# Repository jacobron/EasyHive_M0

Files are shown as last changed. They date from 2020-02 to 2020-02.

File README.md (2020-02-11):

# EasyHive_M0
M0-Board Code (Arduino C++) and Hardware Files V1.3

This Board is designed for the purpose of remote and off-grid temperature and weight measurements.

# Features

* ADS1232 ADC-IC for weight reading up to two load-cells
* ATSAMD21G - CortexM0 Microcontroller - programmable with Arduino Software
* Ublox SaraN200 NB-IOT Chip for sending data via narrowband-LTE
* BQ24072 charging IC for USB/Solar and battery temperature monitoring
* DS18B20 temperatur sensor von Maxim Integrated
* Piezo Buzzer and RGB LED for user communication

The board features additional connections for I2S and I2C sensors, which are not used yet.

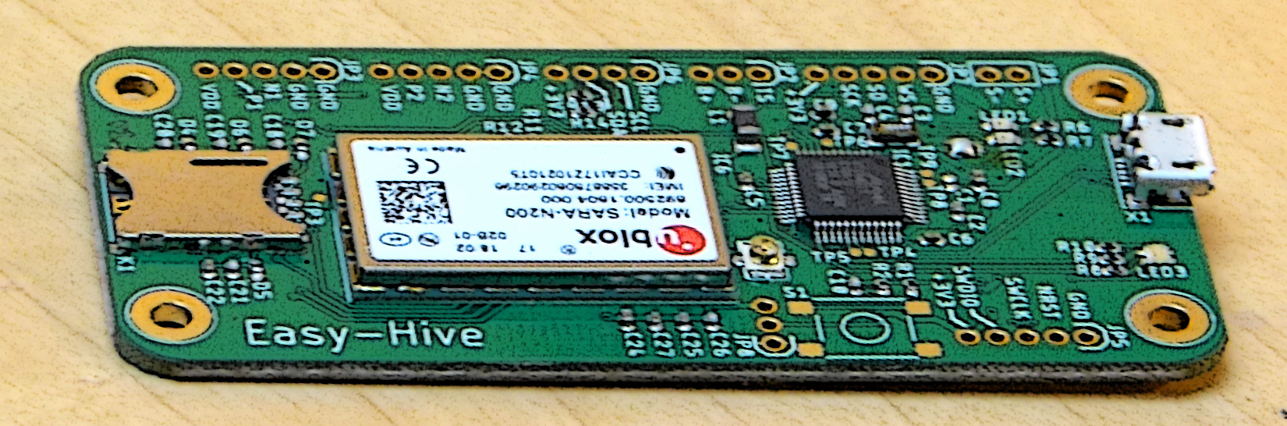
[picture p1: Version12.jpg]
BoardV12


# copyright
Software: GPL 3.0 and following versions

Hardware: CERN OHL 1.2 and following versions

This files are distributed in the hope that it will be useful,
but WITHOUT ANY WARRANTY; without even the implied warranty of
MERCHANTABILITY or FITNESS FOR A PARTICULAR PURPOSE.
See the GNU General Public License for more details.

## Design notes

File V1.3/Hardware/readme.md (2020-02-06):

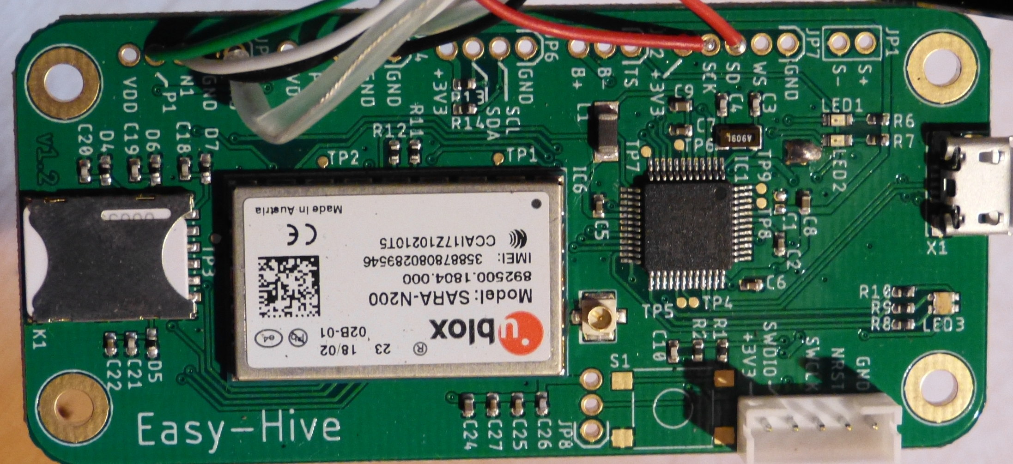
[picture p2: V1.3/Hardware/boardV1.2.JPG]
Board V1.2


# additional information
* steuckliste is missing some LEDs - we won't use them in production run as nobody see's them in the box ;-)

# copyright
CERN OHL 1.2 and following versions

This files are distributed in the hope that it will be useful,
but WITHOUT ANY WARRANTY; without even the implied warranty of
MERCHANTABILITY or FITNESS FOR A PARTICULAR PURPOSE.
See the GNU General Public License for more details.

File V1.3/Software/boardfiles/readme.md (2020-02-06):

# important information
We did not write an own Boardfile-set yet. you need to rewrite the Boardfiles from Sodaq-SFF Board which our design is based on.

more information:

[https://support.sodaq.com/getting_started/](https://support.sodaq.com/getting_started/)

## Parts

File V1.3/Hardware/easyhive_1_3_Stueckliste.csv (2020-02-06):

Id | Designator | Package | Quantity | Designation | Manufacturer | Part nr
1 | IC3 | TSSOP24 | 1 | ADS1232 | TI | ADS1232IPWR
2 | IC1 | TQFP48 | 1 | ATSAMD21G | Microchip Technology | TSAMD21G18A-AUT
3 | C2,C11,C30 | C0402 | 3 | 1u
4 | C3,C4 | C0402 | 2 | 15p
5 | C5,C6,C7,C1,C14,C15,C22,C27,C28 | C0402 | 9 | 100n
6 | C8,C9,C16,C17,C24 | C0402 | 5 | 10u
7 | L1,L2 | SM-1206 | 2 | Ferrite Bead 1k ohm 1LN | WURTH | 742792141 | auch anderer Hersteller möglich
8 | C10 | C0402 | 1 | 100p
9 | R1 | C0402 | 1 | 330
10 | R2,R8 | C0402 | 2 | 2k2
11
12 | D1,D2 | SOD123 | 2 | DIODE SCHOTTKY 20V 500MA SOD123 | ON Semiconductor | MBR0520LT | auch anderer Hersteller möglich
13 | C12,C13,C23 | C0402 | 3 | 4u7
14 | X1 | USBMICRO | 1 | USB_MICRO_SHIELD | Amphenol ICC | 10118193-0001LF
15
16
17 | IC2 | VQFN16 | 1 | BQ2407X | TI | BQ24072RGTT
18 | R3,R11,R12 | C0402 | 3 | 0R
19 | R4 | C0402 | 1 | 1k18
20 | R5 | C0402 | 1 | 680R
21
22 | R6,R7 | C0402 | 2 | 1k
23
24 | R9 | C0402 | 1 | 10k
25 | R10,R18 | C0402 | 2 | 4k7
26 | Q1 | FC135 | 1 | 32768 Hz
27 | IC4 | UMAX8 | 1 | DS18B20U | Maxim Integrated | DS18B20U+
28 | IC5 | SOT25 | 1 | XC6220B331 | Torex Semiconductor | XC6220B331MR-G
29 | K1 | 693043020611 | 1 | SimCard Holder | WÜRTH | 693043020611
30 | IC6 | SARA-N2 | 1 | SARA-N2 | U-blox | Sara N200-02B
31 | C18,C19,C20,C21,C26 | C0402 | 5 | 47p
32 | D5,D4,D6,D7,D8,D9,D10,D11,D12,D13,D14 | 0402-TVS | 11 | PESD0402-140 | Littlefuse | PESD0402-140 | auch anderer Hersteller möglich
33 | C25 | C0402 | 1 | 10n
34 | R13,R14 | C0402 | 2 | 2k
35 | F1 | 1206 | 1 | 6V/0.5A | Bel Fuse Inc | 0ZCJ0050FF2G | auch anderer Hersteller möglich
36
37
38
39
40
41 | J1 | U.FL | 1 | U.FL | Hirose | U.FL-R-SMT-1(01) | auch anderer Hersteller möglich
42
43 | P1 | PKMCS_BUZZER | 1 | PKMCS | Murata | PKMCS0909E4000-R1
44 | R16 | C0402 | 1 | 4M7
45 | R17 | C0402 | 1 | 10M
47 | R15 | C0402 | 1 | NTC 103AT 10k | Abracon | ABNTC-0402-103J-4050F-T | auch anderer Hersteller möglich
48
49 | IC7 | sot-sc70-6 | 1 | TPS22919 | TI | TPS22919DCKR

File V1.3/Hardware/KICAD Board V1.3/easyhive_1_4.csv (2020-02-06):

Id | Designator | Package | Quantity | Designation | Supplier and ref
1 | IC3 | TSSOP24 | 1 | ADS1232
2 | IC1 | TQFP48 | 1 | ATSAMD21G
3 | C2,C11,C30 | C0402 | 3 | 1u
4 | C3,C4 | C0402 | 2 | 15p
5 | C5,C6,C7,C1,C14,C15,C22,C27,C28 | C0402 | 9 | 100n
6 | C8,C9,C16,C17,C24 | C0402 | 5 | 10u
7 | L1,L2 | SM-1206 | 2 | SM-1206
8 | C10 | C0402 | 1 | 100p
9 | R1 | C0402 | 1 | 330
10 | R2,R8 | C0402 | 2 | 2k2
11 | S1 | WURTH-430 | 1 | WURTH-430
12 | D1,D2 | SOD123 | 2 | MBR0520LT
13 | C12,C13,C23 | C0402 | 3 | 4u7
14 | X1 | USBMICRO | 1 | USB_MICRO_SHIELD
15 | JP1 | 1X02_2MM | 1 | Solar
16 | JP2 | 1X03-2MM | 1 | Battery
17 | IC2 | VQFN16 | 1 | BQ2407X
18 | R3,R11,R12 | C0402 | 3 | 0R
19 | R4 | C0402 | 1 | 1k18
20 | R5 | C0402 | 1 | 680R
21 | LED1,LED2 | CHIPLED_0603 | 2 | LEDCHIPLED_0603
22 | R6,R7 | C0402 | 2 | 1k
23 | LED3 | WL-SFCX_0606 | 1 | WL-SFCD_0606_150066M153000
24 | R9 | C0402 | 1 | 10k
25 | R10,R18 | C0402 | 2 | 4k7
26 | Q1 | FC135 | 1 | 32768 Hz
27 | IC4 | UMAX8 | 1 | DS18B20U
28 | IC5 | SOT25 | 1 | XC6220B331
29 | K1 | 693043020611 | 1 | 693043020611
30 | IC6 | SARA-N2 | 1 | SARA-N2
31 | C18,C19,C20,C21,C26 | C0402 | 5 | 47p
32 | D5,D4,D6,D7,D8,D9,D10,D11,D12,D13,D14 | 0402-TVS | 11 | PESD0402-140
33 | C25 | C0402 | 1 | 10n
34 | R13,R14 | C0402 | 2 | 2k
35 | F1 | 1206 | 1 | 6V/0.5A
36 | H1,H2,H3,H4 | 2,8-PAD | 4 | MOUNT-PAD-ROUND2.8
37 | JP3 | 1X05-2MM | 1 | Sens1
38 | JP4 | 1X05-2MM | 1 | Sens2
39 | JP6 | 1X04-2MM | 1 | I2C
40 | JP5 | 1X05-2MM | 1 | SWD
41 | J1 | U.FL | 1 | U.FL
42 | JP7 | 1X05-2MM | 1 | I2S
43 | P1 | PKMCS_BUZZER | 1 | PKMCS
44 | R16 | C0402 | 1 | 4M7
45 | R17 | C0402 | 1 | 10M
46 | TP1,TP2,TP3,TP4,TP6,TP8,TP9,TP10,TP11,TP12,TP7 | TP08R | 11 | TPTP08R
47 | R15 | C0402 | 1 | NTC 103AT
48 | JP8 | 1X03-2MM | 1 | ext. DS18B20
49 | IC7 | sot-sc70-6 | 1 | TPS22919

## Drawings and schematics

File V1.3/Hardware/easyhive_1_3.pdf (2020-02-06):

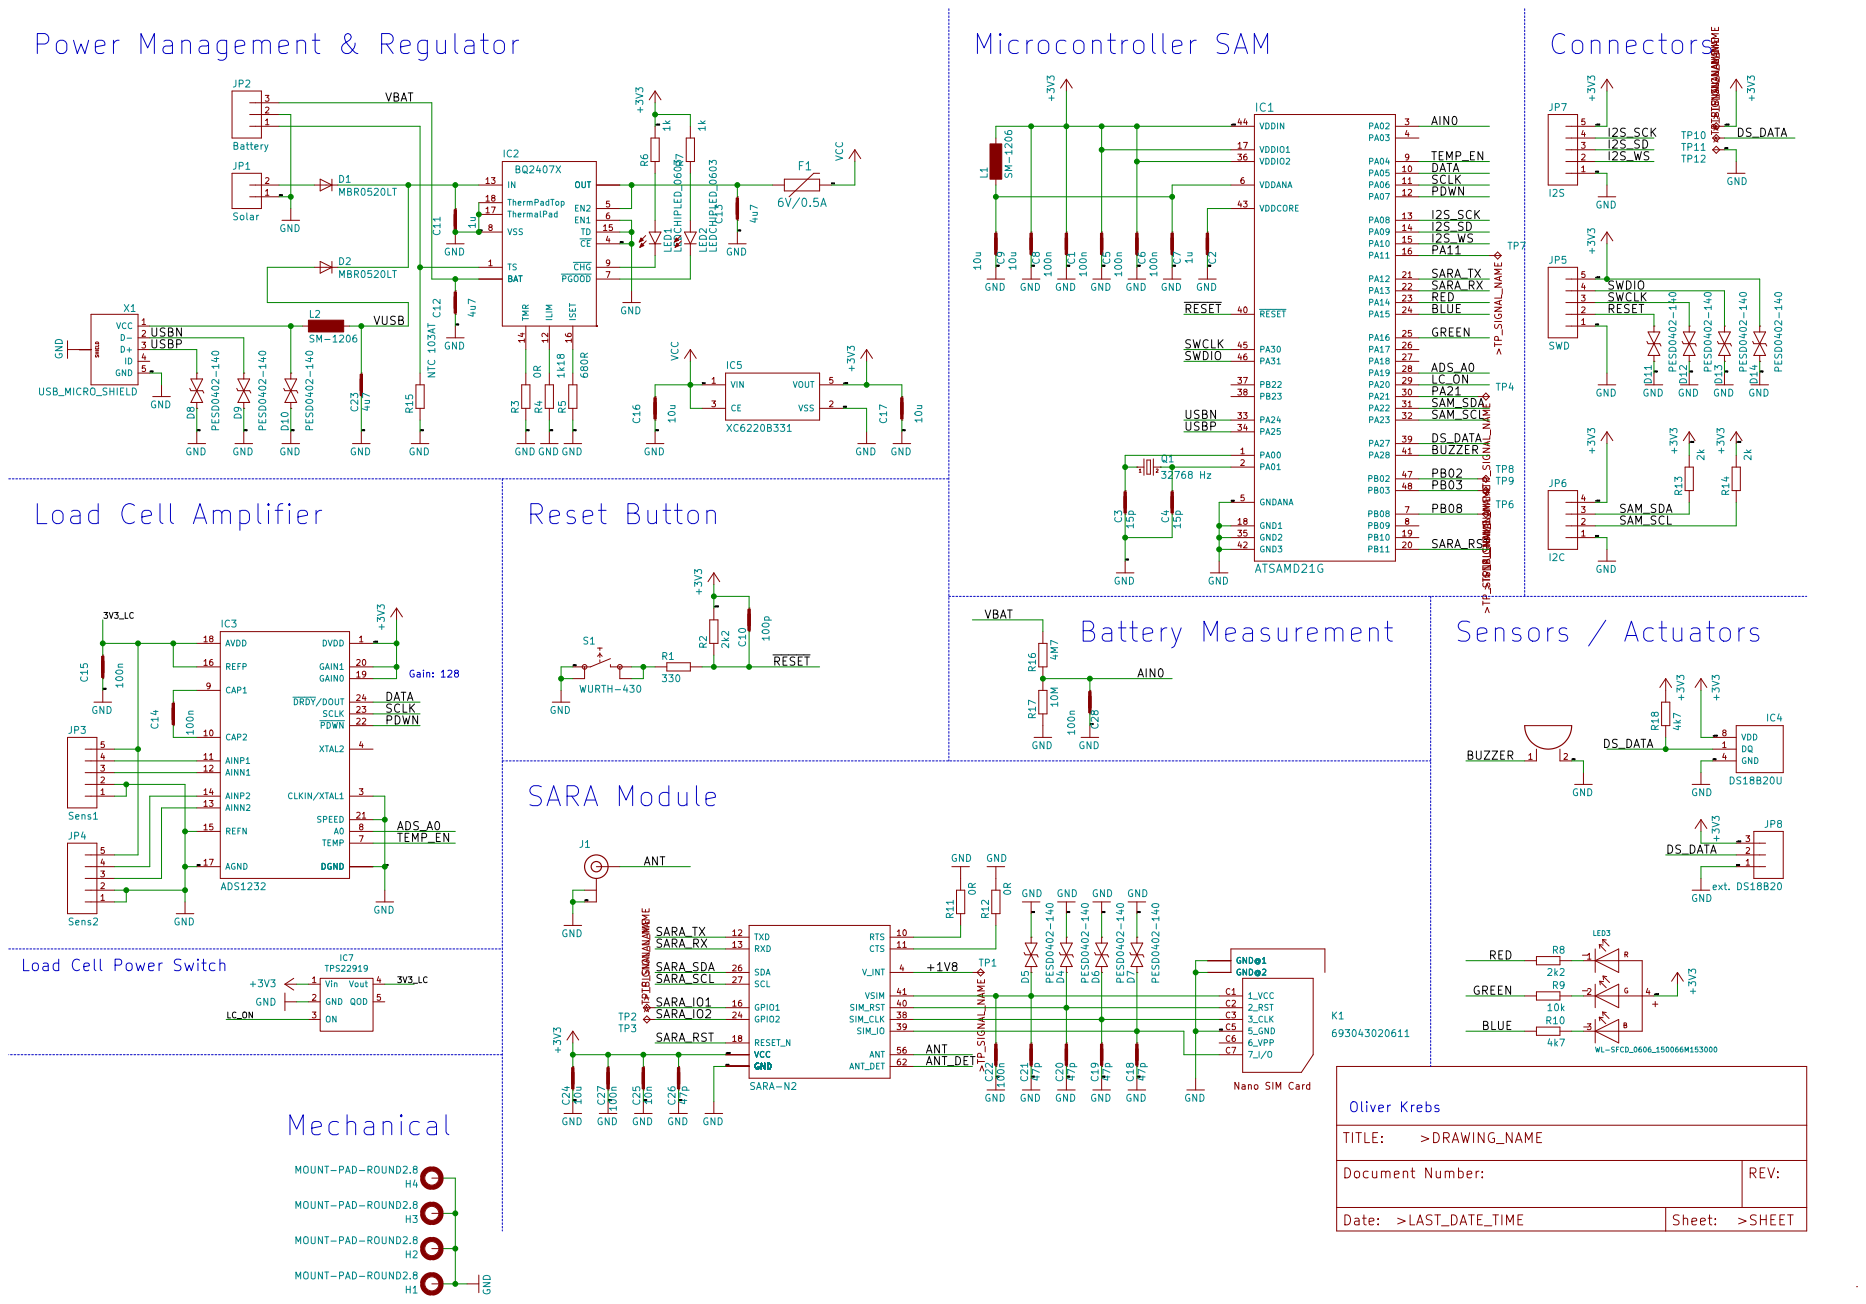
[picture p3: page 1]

Load Cell Power Switch

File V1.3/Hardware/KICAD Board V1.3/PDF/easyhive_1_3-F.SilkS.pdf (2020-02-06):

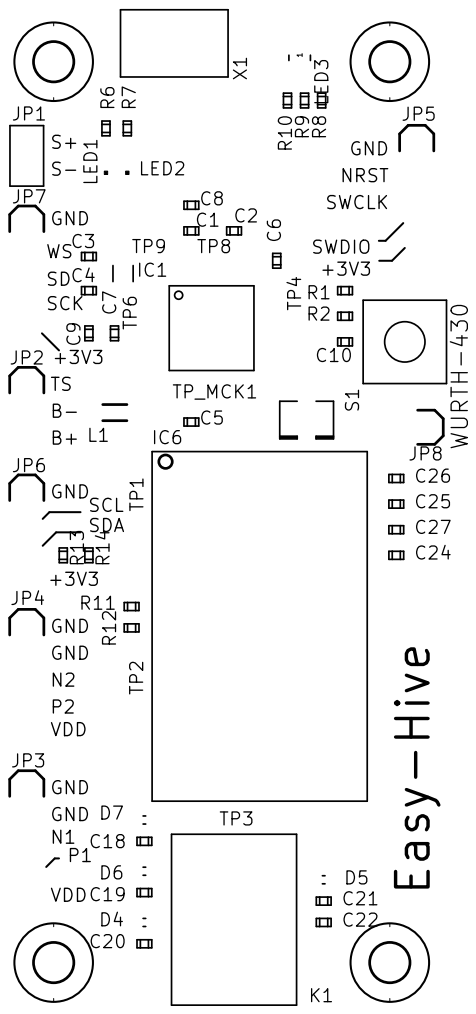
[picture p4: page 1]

+3V3 GND GND GND GND GND GND

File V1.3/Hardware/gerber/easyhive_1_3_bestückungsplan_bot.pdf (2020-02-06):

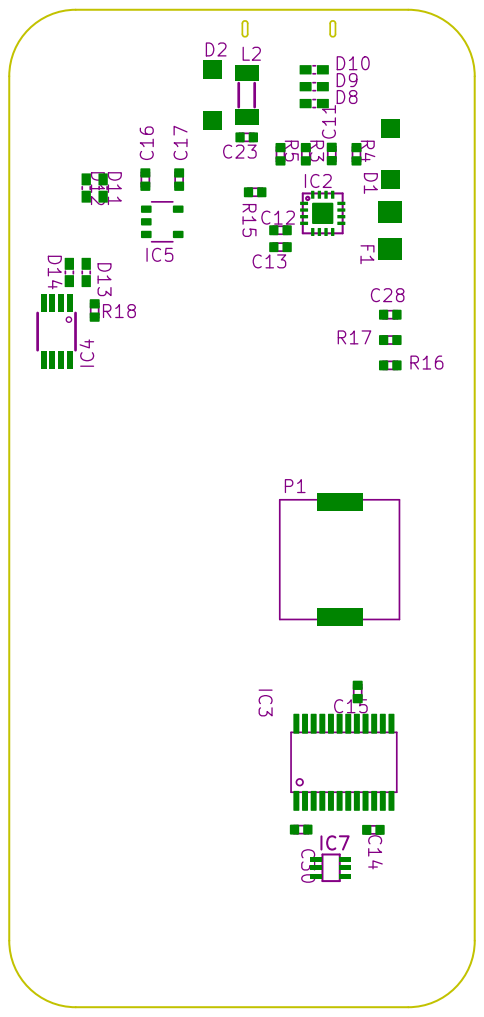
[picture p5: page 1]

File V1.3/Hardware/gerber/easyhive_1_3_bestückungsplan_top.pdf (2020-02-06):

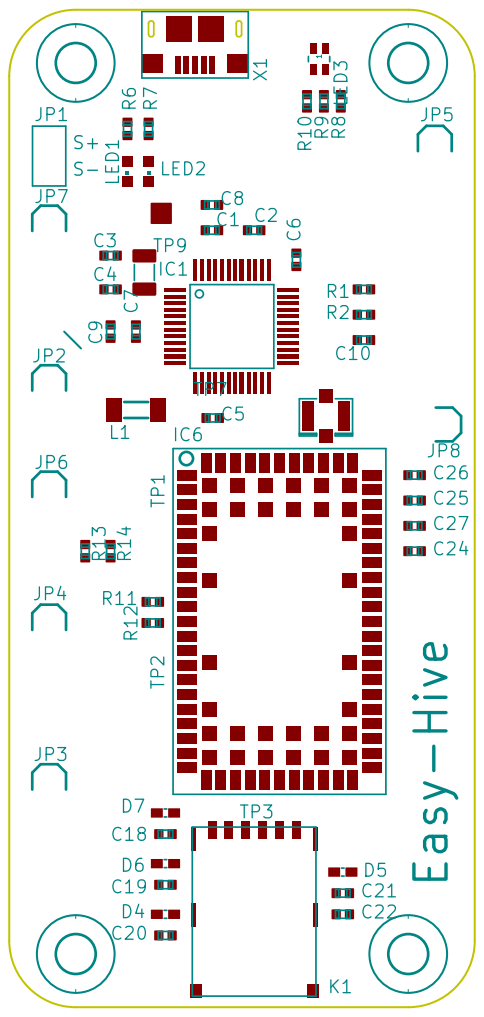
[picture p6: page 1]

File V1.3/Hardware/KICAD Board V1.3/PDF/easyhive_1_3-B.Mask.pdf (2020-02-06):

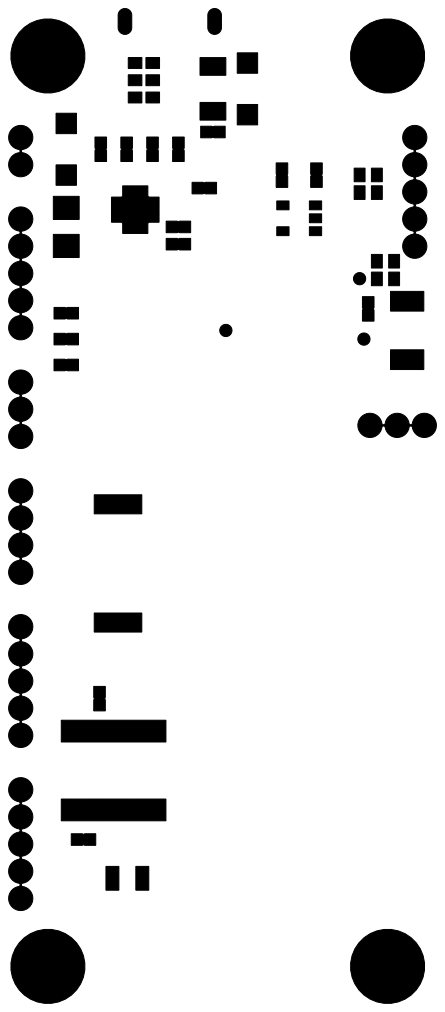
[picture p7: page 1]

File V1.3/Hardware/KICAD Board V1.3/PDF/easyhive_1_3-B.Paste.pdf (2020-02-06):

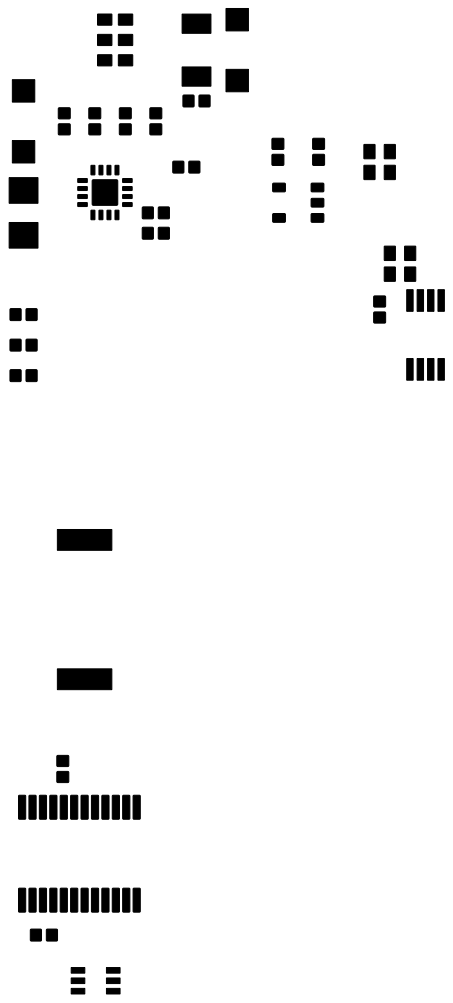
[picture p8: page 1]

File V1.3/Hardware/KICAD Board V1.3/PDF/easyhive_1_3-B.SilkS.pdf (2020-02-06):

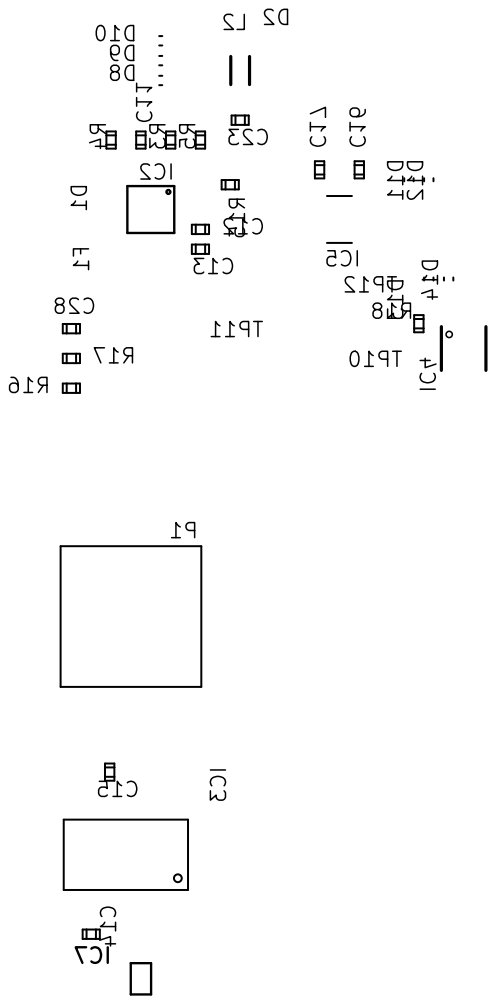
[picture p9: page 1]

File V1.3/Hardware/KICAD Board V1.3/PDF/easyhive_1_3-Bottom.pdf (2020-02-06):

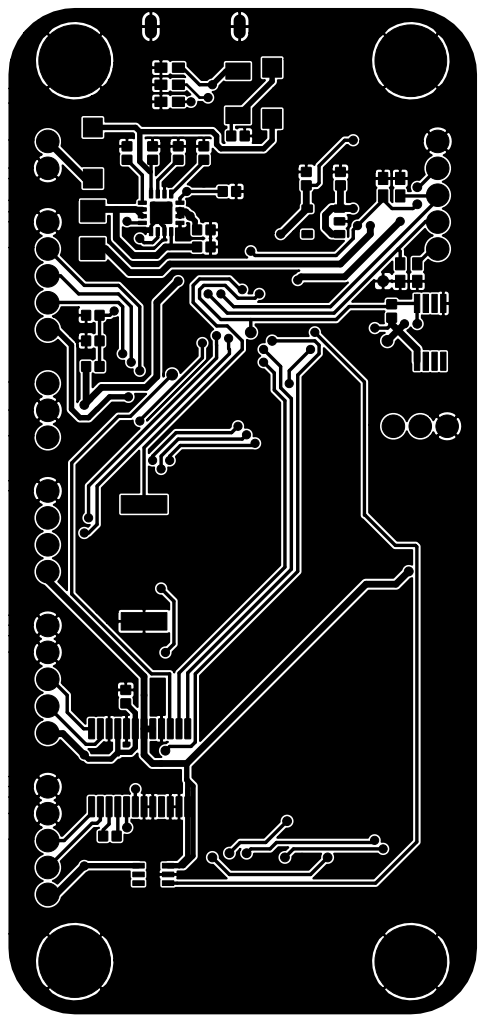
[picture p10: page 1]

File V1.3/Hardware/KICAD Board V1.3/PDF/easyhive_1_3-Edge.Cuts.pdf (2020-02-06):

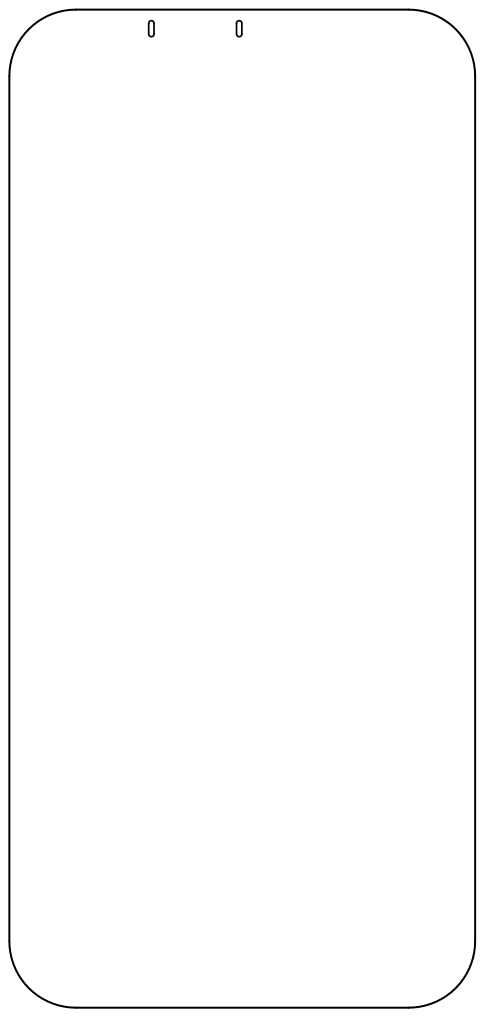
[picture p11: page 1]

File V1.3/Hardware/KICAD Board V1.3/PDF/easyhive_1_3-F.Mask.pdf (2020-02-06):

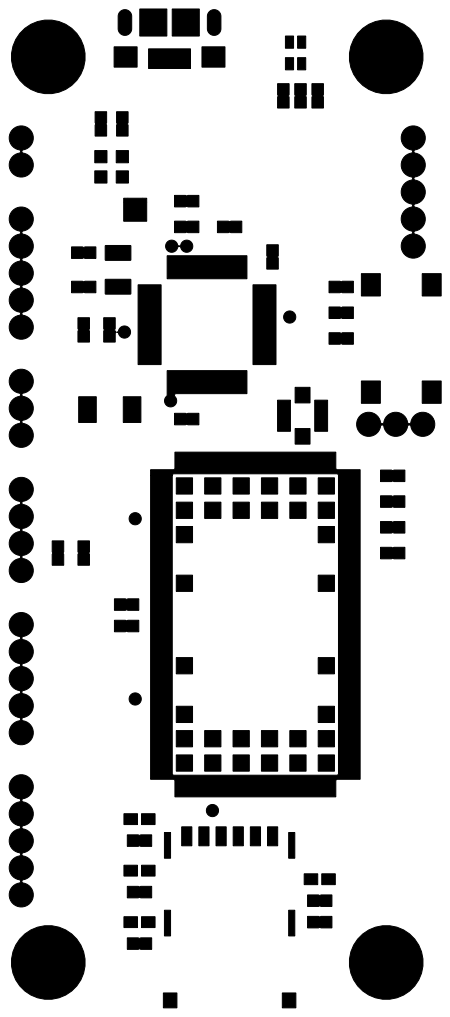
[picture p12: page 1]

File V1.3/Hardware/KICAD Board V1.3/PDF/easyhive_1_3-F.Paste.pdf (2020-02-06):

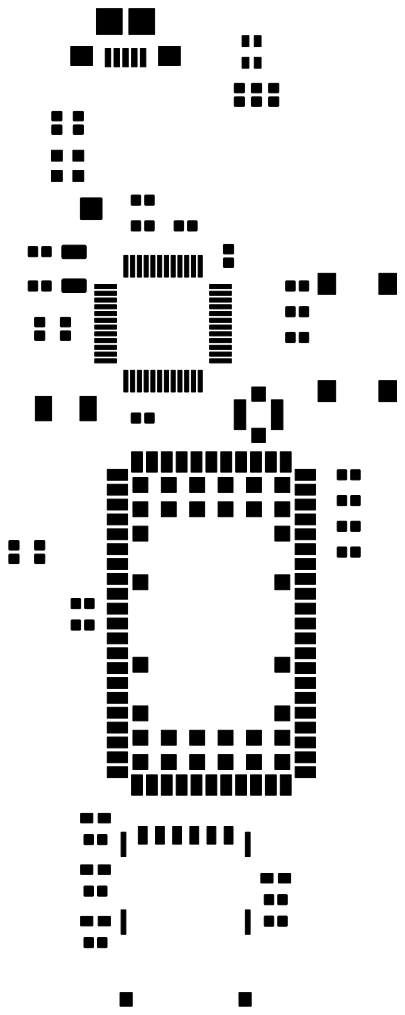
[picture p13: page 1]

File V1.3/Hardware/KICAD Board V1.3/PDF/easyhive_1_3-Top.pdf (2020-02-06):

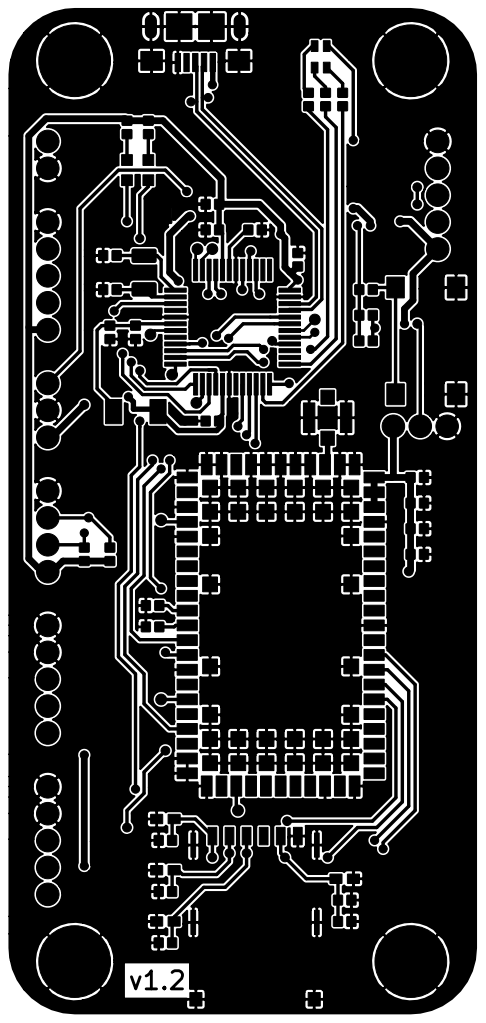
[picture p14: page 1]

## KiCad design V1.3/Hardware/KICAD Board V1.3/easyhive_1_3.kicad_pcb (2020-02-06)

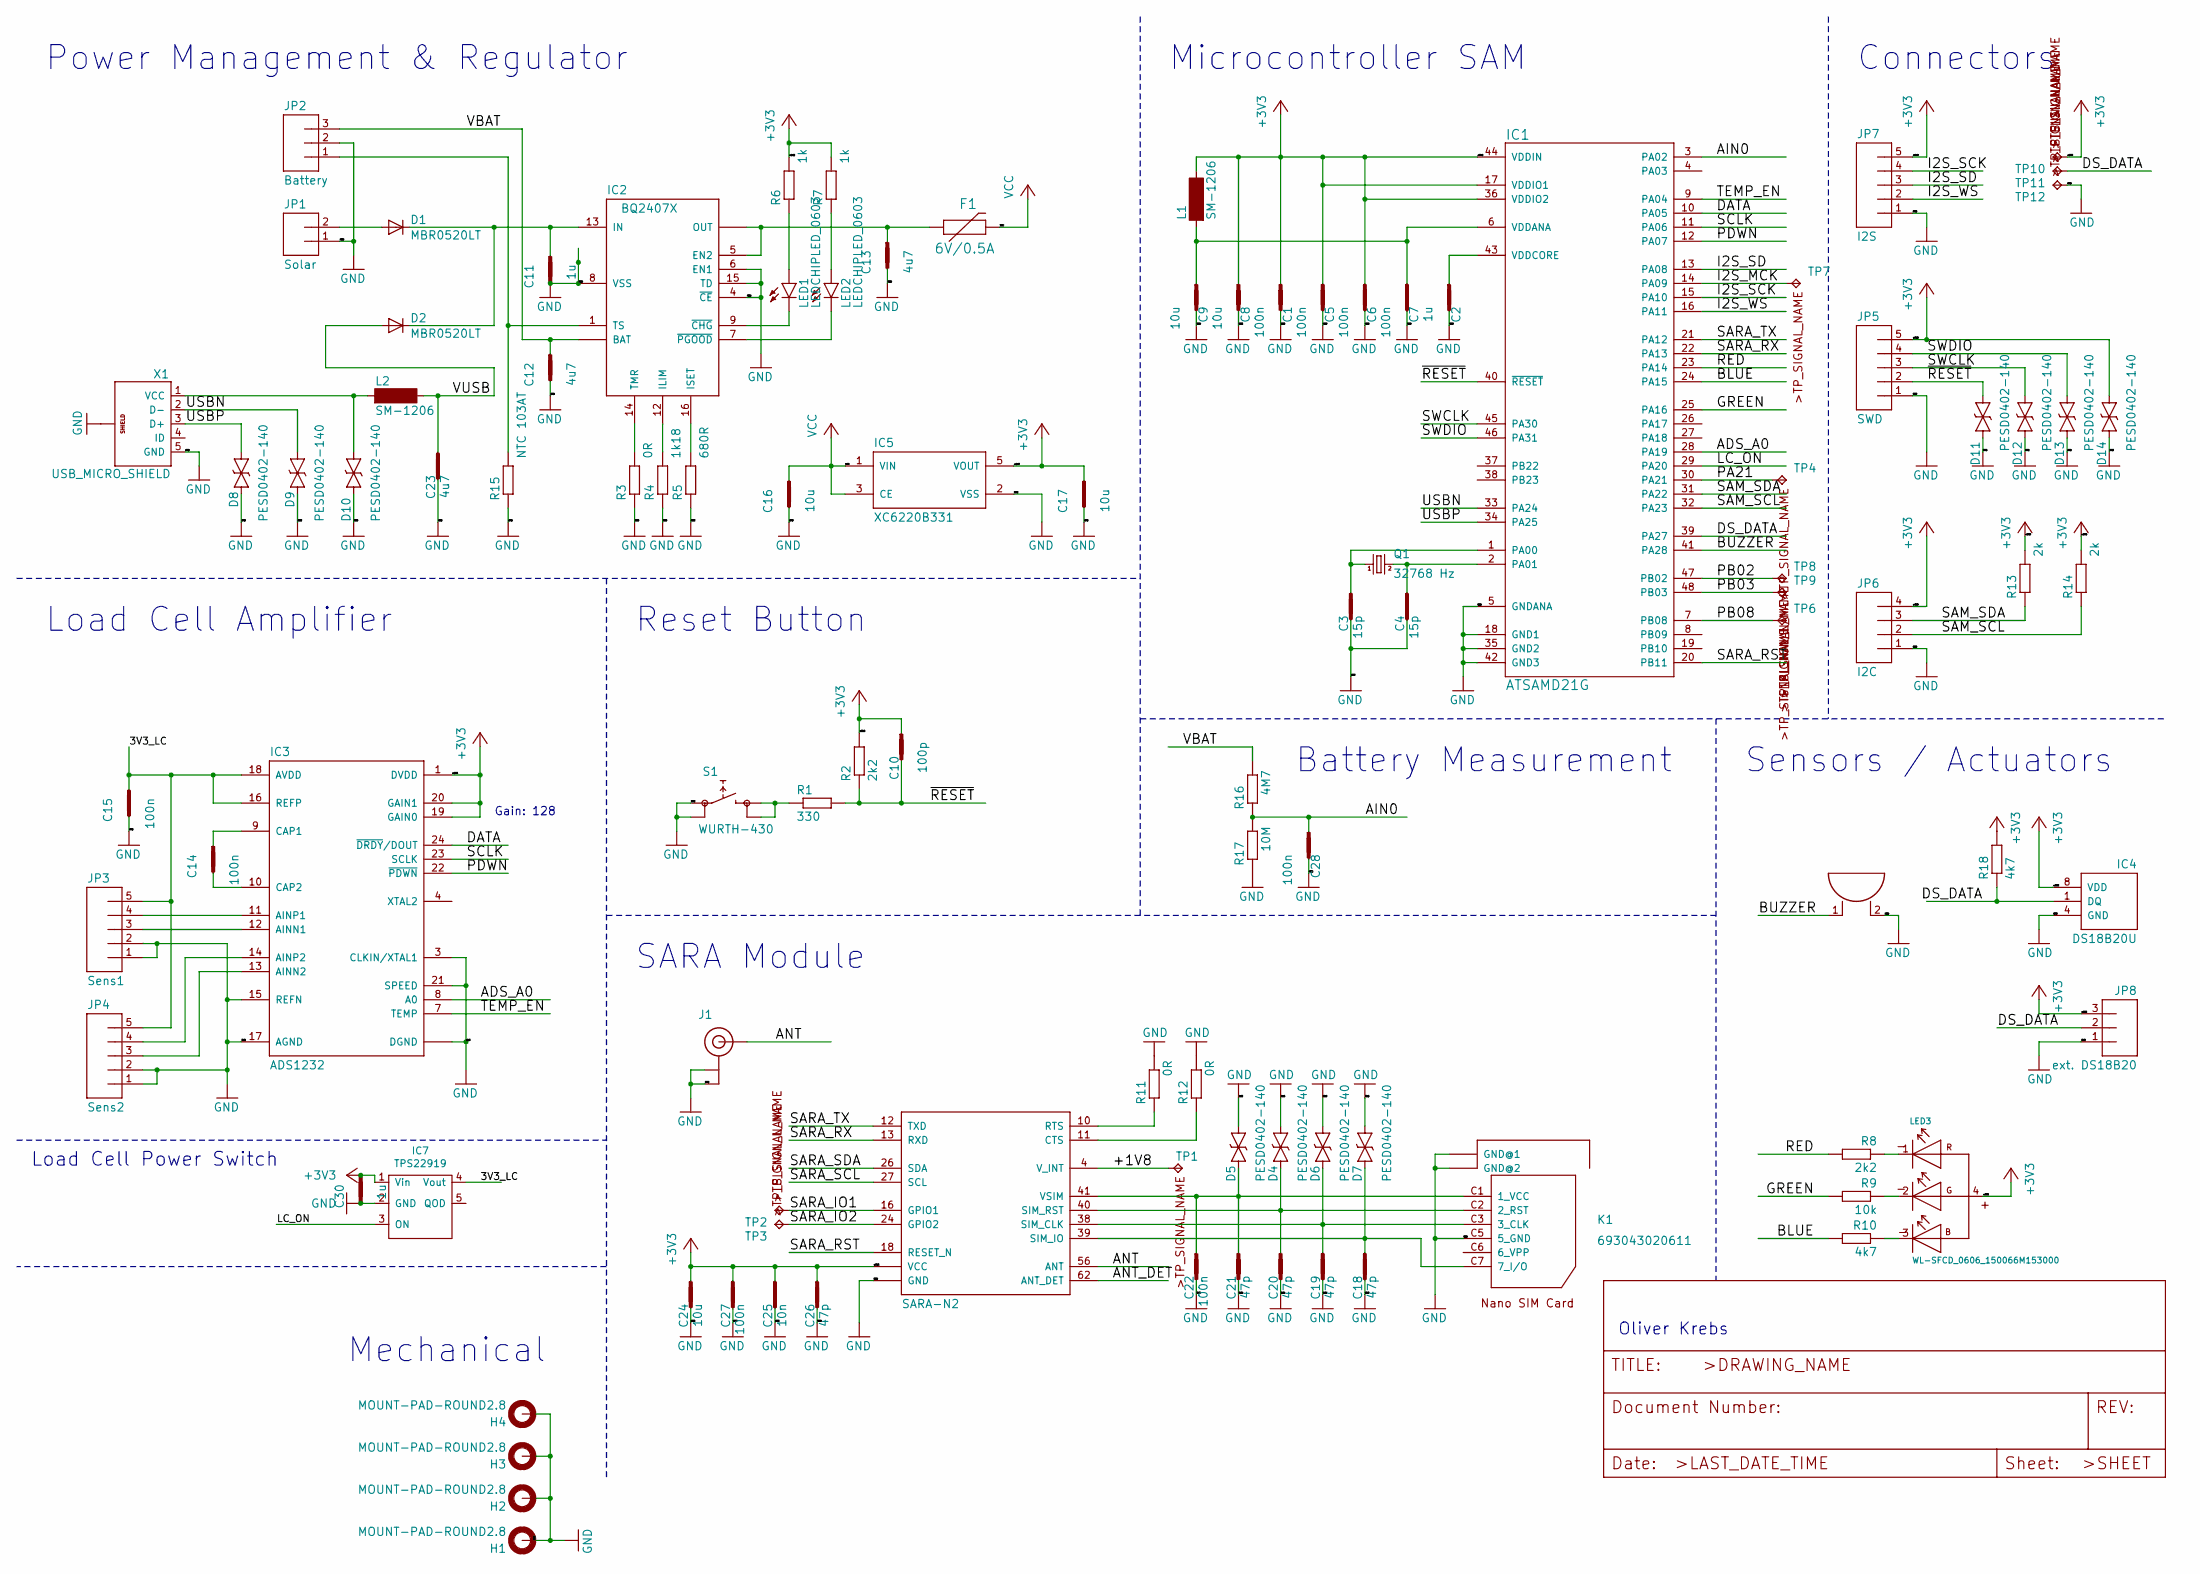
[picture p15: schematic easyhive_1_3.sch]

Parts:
C1, C5, C6, C7, C14, C15, C22, C27, C28: 100n; C0402
C2, C11, C30: 1u; C0402
C3, C4: 15p; C0402
C8, C9, C16, C17, C24: 10u; C0402
C10: 100p; C0402
C12, C13, C23: 4u7; C0402
C18, C19, C20, C21, C26: 47p; C0402
C25: 10n; C0402
D1, D2: MBR0520LT; SOD123
D4, D5, D6, D7, D8, D9, D10, D11, D12, D13, D14: PESD0402-140; 0402-TVS
F1: 6V/0.5A; 1206
H1, H2, H3, H4: MOUNT-PAD-ROUND2.8; 2,8-PAD
IC1: ATSAMD21G; TQFP48
IC2: BQ2407X; VQFN16
IC3: ADS1232; TSSOP24
IC4: DS18B20U; UMAX8
IC5: XC6220B331; SOT25
IC6: SARA-N2
IC7: TPS22919; sot-sc70-6
J1: U.FL
JP1: Solar; 1X02_2MM
JP2: Battery; 1X03-2MM
JP3: Sens1; 1X05-2MM
JP4: Sens2; 1X05-2MM
JP5: SWD; 1X05-2MM
JP6: I2C; 1X04-2MM
JP7: I2S; 1X05-2MM
JP8: ext. DS18B20; 1X03-2MM
K1: 693043020611
L1, L2: SM-1206
LED1, LED2: LEDCHIPLED_0603; CHIPLED_0603
LED3: WL-SFCD_0606_150066M153000; WL-SFCX_0606
P1: PKMCS; PKMCS_BUZZER
Q1: 32768 Hz; FC135
R1: 330; C0402
R2, R8: 2k2; C0402
R3, R11, R12: 0R; C0402
R4: 1k18; C0402
R5: 680R; C0402
R6, R7: 1k; C0402
R9: 10k; C0402
R10, R18: 4k7; C0402
R13, R14: 2k; C0402
R15: NTC 103AT; C0402
R16: 4M7; C0402
R17: 10M; C0402
S1: WURTH-430
TP1, TP2, TP3, TP4, TP6, TP7, TP8, TP9, TP10, TP11, TP12: TPTP08R; TP08R
X1: USB_MICRO_SHIELD; USBMICRO

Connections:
+3V3: C1.1, C5.1, C6.1, C8.1, C10.1, C17.1, C24.1, C25.1, C26.1, C27.1, C30.1, D14.P$2 (C), IC1.17 (VDDIO1), IC1.36 (VDDIO2), IC1.44 (VDDIN), IC3.1 (DVDD), IC3.19 (GAIN0), IC3.20 (GAIN1), IC4.8 (VDD), IC5.5 (VOUT), IC6.51 (VCC), IC6.52 (VCC), IC6.53 (VCC), IC7.1 (Vin), JP5.5, JP6.4, JP7.5, JP8.3, L1.2, LED3.4, R2.2, R6.2, R7.2, R13.2, R14.2, R18.2, TP10.TP
/3V3_LC: C15.1, IC3.16 (REFP), IC3.18 (AVDD), IC7.4 (Vout), JP3.5, JP4.5
/+1V8: IC6.4 (V_INT), TP1.TP
/ADS_A0: IC1.28 (PA19), IC3.8 (A0)
/AIN0: C28.1, IC1.3 (PA02), R16.1, R17.2
/ANT: IC6.56 (ANT), J1.P$3 (SIGNAL)
/ANT_DET: IC6.62 (ANT_DET)
/BLUE: IC1.24 (PA15), R10.2
/BUZZER: IC1.41 (PA28), P1.1
/DATA: IC1.10 (PA05), IC3.24 (~DRDY~/DOUT)
/DS_DATA: IC1.39 (PA27), IC4.1 (DQ), JP8.2, R18.1, TP11.TP
/GREEN: IC1.25 (PA16), R9.2
/I2S_MCK: IC1.14 (PA09), TP7.TP
/I2S_SCK: IC1.15 (PA10), JP7.4
/I2S_SD: IC1.13 (PA08), JP7.3
/I2S_WS: IC1.16 (PA11), JP7.2
/LC_ON: IC1.29 (PA20), IC7.3 (ON)
/PA21: IC1.30 (PA21), TP4.TP
/PB02: IC1.47 (PB02), TP8.TP
/PB03: IC1.48 (PB03), TP9.TP
/PB08: IC1.7 (PB08), TP6.TP
/PDWN: IC1.12 (PA07), IC3.22 (~PDWN)
/RED: IC1.23 (PA14), R8.2
/SAM_SCL: IC1.32 (PA23), JP6.2, R14.1
/SAM_SDA: IC1.31 (PA22), JP6.3, R13.1
/SARA_IO1: IC6.16 (GPIO1), TP2.TP
/SARA_IO2: IC6.24 (GPIO2), TP3.TP
/SARA_RST: IC1.20 (PB11), IC6.18 (RESET_N)
/SARA_RX: IC1.22 (PA13), IC6.13 (RXD)
/SARA_SCL: IC6.27 (SCL)
/SARA_SDA: IC6.26 (SDA)
/SARA_TX: IC1.21 (PA12), IC6.12 (TXD)
/SCLK: IC1.11 (PA06), IC3.23 (SCLK)
/SWCLK: D12.P$2 (C), IC1.45 (PA30), JP5.3
/SWDIO: D13.P$2 (C), IC1.46 (PA31), JP5.4
/TEMP_EN: IC1.9 (PA04), IC3.7 (TEMP)
/USBN: D9.P$2 (C), IC1.33 (PA24), X1.2 (D-)
/USBP: D8.P$2 (C), IC1.34 (PA25), X1.3 (D+)
/VBAT: C12.1, IC2.2 (BAT), IC2.3 (BAT), JP2.3, R16.2
/VUSB: C23.1, D2.A, L2.2
/~RESET: C10.2, D11.P$2 (C), IC1.40 (~RESET), JP5.2, R1.2, R2.1
unnamed: C2.1, IC1.43 (VDDCORE)
unnamed: C3.1, IC1.1 (PA00), Q1.1
unnamed: C4.1, IC1.2 (PA01), Q1.2
unnamed: C7.1, C9.1, IC1.6 (VDDANA), L1.1
unnamed: C11.1, D1.C, D2.C, IC2.13 (IN)
unnamed: C13.1, F1.1, IC2.5 (EN2), IC2.10 (OUT), IC2.11 (OUT)
unnamed: C14.1, IC3.9 (CAP1)
unnamed: C14.2, IC3.10 (CAP2)
unnamed: C18.1, D7.P$1 (A), IC6.39 (SIM_IO), K1.C7 (7_I/O)
unnamed: C19.1, D6.P$1 (A), IC6.38 (SIM_CLK), K1.C3 (3_CLK)
unnamed: C20.1, D4.P$1 (A), IC6.40 (SIM_RST), K1.C2 (2_RST)
unnamed: C21.1, C22.1, D5.P$1 (A), IC6.41 (VSIM), K1.C1 (1_VCC)
unnamed: D1.A, JP1.2
unnamed: D10.P$2 (C), L2.1, X1.1 (VCC)
unnamed: IC2.1 (TS), JP2.1, R15.2
unnamed: IC2.7 (~PGOOD), LED2.C
unnamed: IC2.9 (~CHG), LED1.C
unnamed: IC2.12 (ILIM), R4.2
unnamed: IC2.14 (TMR), R3.2
unnamed: IC2.16 (ISET), R5.2
unnamed: IC3.11 (AINP1), JP3.4
unnamed: IC3.12 (AINN1), JP3.3
unnamed: IC3.13 (AINN2), JP4.3
unnamed: IC3.14 (AINP2), JP4.4
unnamed: IC6.10 (RTS), R11.1
unnamed: IC6.11 (CTS), R12.1
unnamed: LED1.A, R6.1
unnamed: LED2.A, R7.1
unnamed: LED3.1 (R), R8.1
unnamed: LED3.2 (G), R9.1
unnamed: LED3.3 (B), R10.1
unnamed: R1.1, S1.2 (1@A), S1.4 (1@B)
VCC: C16.1, F1.2, IC5.1 (VIN), IC5.3 (CE)

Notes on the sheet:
Gain: 128
Oliver Krebs
Power Management & Regulator
Microcontroller SAM
SARA Module
Load Cell Amplifier
Connectors
Sensors / Actuators
Mechanical
Reset Button
Battery Measurement
Load Cell Power Switch

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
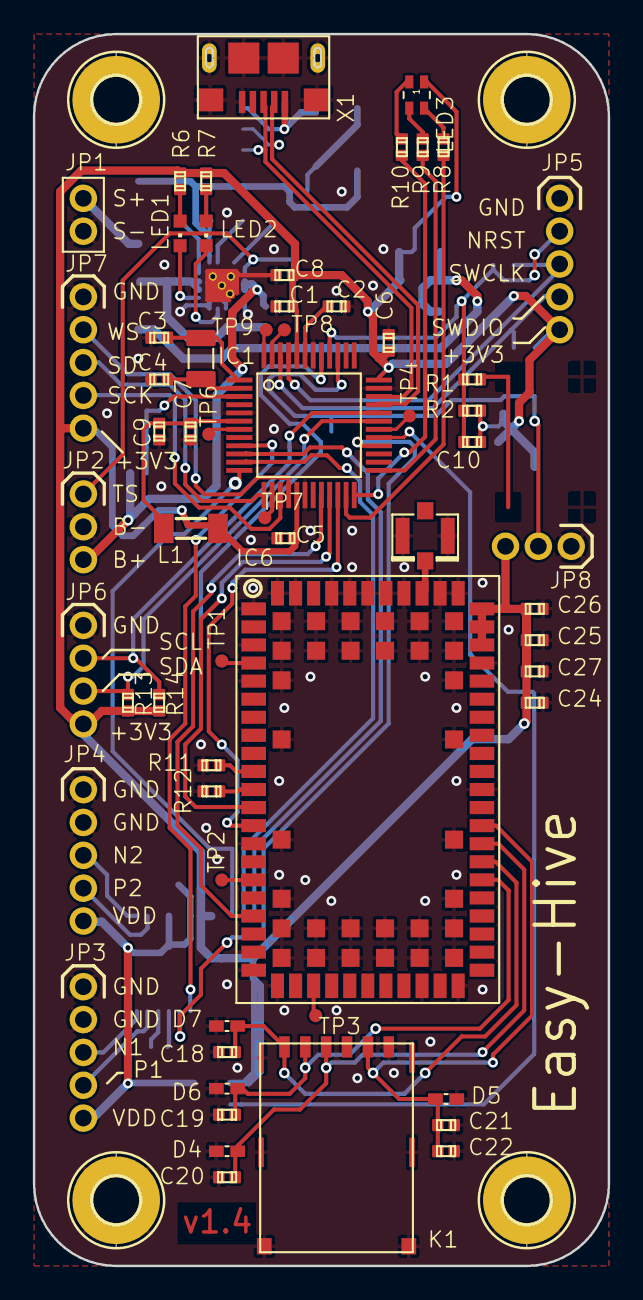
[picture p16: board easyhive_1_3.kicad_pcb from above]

Board: 2 copper layers, 35.0 x 75.0 mm, 101 parts (0 on the bottom side), 72 nets.

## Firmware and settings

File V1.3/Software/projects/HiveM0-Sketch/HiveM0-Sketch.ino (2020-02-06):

//###################################################
// Include the libraries we need

#include "OneWire.h"
#include "DallasTemperature.h"
#include "ADS1231.h"
#include "Sodaq_nbIOT.h"
#include "Sodaq_wdt.h"
#include "FlashStorage.h"
#include "EasyHive.h"
#include "rtttl.h"

char *startup = "OneMoreT:d=16,o=5,b=250:3a7,4p,3a7,4p,3a7,4p,3b7,4p,3b7,4p";

extern int BoardID;
extern int datalogtime;
extern int datasendtime;
int loopcounter;

extern Sodaq_nbIOT nbiot;
// Server variables
// define Server variables
extern const char* apn;
extern const char* cdp;
extern unsigned char cid;
extern const char* forceOperator; // optional - depends on SIM / network

int8_t SIGNAL;
uint8_t BER;

/*
   The setup function. We only start the sensors here and initialize the board state
*/

// Reserve a portion of flash memory to store an "bool" variable
// and call it "calibrated".
//FlashStorage(test, float);

void setup(void)
{
  play_rtttl(startup);
  tone(BUZZER,4000);
  delay(100);
  noTone(BUZZER);
  
  sodaq_wdt_safe_delay(5000);


  init_LEDs();
  LEDs_red();
  delay(1000);
  LEDs_green();
  delay(1000);
  LEDs_blue();
  delay(1000);
  LEDs_off();

  // init_RTC();
  init_server_data();
  init_BoardID();
  init_Temp();
  init_Weight();

  float w_calib;
  float w_offset;
  float w_cweight;
  get_Weight_calib(&w_calib, &w_offset, &w_cweight);
  SerialUSB.println("calib1");
  SerialUSB.println(w_calib);
  SerialUSB.println(w_offset);

  float w_calib2;
  float w_offset2;
  float w_cweight2;
  get_Weight_calib2(&w_calib2, &w_offset2, &w_cweight2);
  SerialUSB.println("calib2");
  SerialUSB.println(w_calib2);
  SerialUSB.println(w_offset2);


  // TEST
  pinMode(LC_ON, OUTPUT);
  digitalWrite(LC_ON, LOW);

  //this code is needed to setup watchdogtimer and to make MCU sleep
  sodaq_wdt_enable(WDT_PERIOD_8X); // watchdog expires in ~8 seconds
  sodaq_wdt_reset(); // restting the watchdog
  initSleep();


  //param1 = calib_val (at 1000g); param2 = offset_val(at 0g);
  //set_Weight_calib(1622203.0, -329233);
  //set_Weight_calib(12345.0, 42.0);

  //test.write(1.23);

  //enable_USB_in();

  /****** nbiot init *******/


  DEBUG_STREAM.begin(DEBUG_STREAM_BAUD);
  DEBUG_STREAM.println("Initializing and connecting... ");

  MODEM_STREAM.begin(nbiot.getDefaultBaudrate());
  nbiot.setDiag(DEBUG_STREAM);
  nbiot.init(MODEM_STREAM, powerPin, enablePin, -1, cid);

  if (!nbiot.connect(apn, cdp, forceOperator, 8)) {
    DEBUG_STREAM.println("Failed to connect to the modem!");
  }

  // check Signal quality
  nbiot.getRSSIAndBER(&SIGNAL, &BER);

  // read Battery voltage
  float VOLT = getBatteryVoltage();

  //send Message and check answer
  // [FLOAT], [FLOAT], [FLOAT], [FLOAT], [INT8_T], [INTEGER], [LONG]
  // [WEIGHT1],[WEIGHT2],[TEMP],[VOLT],[SIGNALQUALITY],[BOARDID],[PAKETNR/EPOCH]
  String startmsg = "Hello!,,," + String(VOLT) + "," + String(SIGNAL) + "," + String(BoardID);
  if (sendMessageThroughUDP(startmsg.c_str())) {
    DEBUG_STREAM.println("FINE!");
  }
  else
  {
    DEBUG_STREAM.println("NO RESPONSE");
  }

  // DEBUG_STREAM.println(sendMessageThroughUDP("Hello!"));
}

/*
   Main function, get and show the temperature, weight and sleep, send data via NB-IoT
*/
void loop(void)
{
  unsigned long loopstarttime = millis();
  loopcounter++;

  // start loadcellstuff
  digitalWrite(LC_ON, HIGH);
  digitalWrite(PDWN, HIGH);

  float temp_val = get_Temp();
  SerialUSB.print("Temp: ");
  SerialUSB.println(temp_val);
  delay(1000);


  digitalWrite(SELECT, LOW);
  //dummy weight measure for settlement
  get_Weight();
  get_Weight();

  float weight_val1 = get_Weight();
  SerialUSB.print("Weight: ");
  SerialUSB.println(weight_val1);
  delay(500);

  long weight_val_raw1 = get_Weight_raw();
  SerialUSB.print("Weight Raw: ");
  SerialUSB.println(weight_val_raw1, DEC);
  delay(500);

  digitalWrite(SELECT, HIGH); // read the other side
  delay(1000);
  //dummy weight measure for settlement
  get_Weight_raw();
  get_Weight_raw();

  float weight_val2 = get_Weight2();
  SerialUSB.print("Weight2: ");
  SerialUSB.println(weight_val2);

  long weight_val_raw2 = get_Weight_raw();
  SerialUSB.print("Weight Raw: ");
  SerialUSB.println(weight_val_raw2, DEC);
  delay(500);

  // check Signal quality
  nbiot.getRSSIAndBER(&SIGNAL, &BER);

  // read Battery voltage
  float VOLT = getBatteryVoltage();
  //read Time from rtc
  long epochtime = get_time();

  // [FLOAT], [FLOAT], [FLOAT], [FLOAT], [INT8_T], [INTEGER], [LONG]
  // [WEIGHT1],[WEIGHT2],[TEMP],[VOLT],[SIGNALQUALITY],[BOARDID],[Package/EPOCH]

  safe_sens_value(weight_val1, weight_val2, temp_val, VOLT, SIGNAL, epochtime );
  

  // String msg = String(weight_val1) + "," + String(weight_val2) + "," + String(temp_val) + "," + String(VOLT) + "," + String(SIGNAL) + "," + String(BoardID) + "," + String(package) ;

  //float w_calib;
  //float w_offset;
  //get_Weight_calib(&w_calib, &w_offset);
  //SerialUSB.println(w_calib);
  //SerialUSB.println(w_offset);

  if (loopcounter >= datasendtime / datalogtime) {
    if (!nbiot.isConnected()) {
      if (!nbiot.connect(apn, cdp, forceOperator, 8)) {
        DEBUG_STREAM.println("Failed to connect to the modem!");
      }
    }
    else {
      for (int i = 0; i > -loopcounter && i > -SENSOR_BUFFER_LEN; i--) {
        float weight1 = 0;
        float weight2 = 0;
        float temp = 0;
        float volt = 0;
        int8_t csq = 0;
        long epoch = 0;

        int pointer_pos = get_sens_pointer(i);
        read_sens_value(&weight1, &weight2, &temp, &volt, &csq, &epoch, pointer_pos);
        String msg = String(weight1) + "," + String(weight2) + "," + String(temp) + "," + String(volt) + "," + String(csq) + "," + String(BoardID) + "," + String(epoch) ;

        sendMessageThroughUDP(msg.c_str());
        // TODO: Was macht er denn falls Senden schiefläuft? Daten verwerfen?
      }
    }
    loopcounter = 0;
  }
  else {
    SerialUSB.print("logging data...");
    // write data to to the logs

    float weight1 = 0;
    float weight2 = 0;
    float temp = 0;
    float volt = 0;
    int8_t csq = 0;
    long pktnr = 0;

    int pointer_pos = get_sens_pointer(0);
    read_sens_value(&weight1, &weight2, &temp, &volt, &csq, &pktnr, pointer_pos);
    delay(100);
    SerialUSB.println("\n ");
    SerialUSB.print("Temp: ");
    SerialUSB.println(temp);
    SerialUSB.print("Weight1 ");
    SerialUSB.println(weight1);
    SerialUSB.print("Weigh2   ");
    SerialUSB.println(weight2);
    SerialUSB.print("volt ");
    SerialUSB.println(volt);
    SerialUSB.print("signal ");
    SerialUSB.println(csq);
    SerialUSB.print("package ");
    SerialUSB.println(pktnr);
  }
  
  digitalWrite(SELECT, LOW);
  digitalWrite(LC_ON, LOW);
  digitalWrite(PDWN, LOW);

  // calculate sleeptime
  int sleeptime = datalogtime - (millis() - loopstarttime)/1000;
  SerialUSB.print("Sleeptime[s]:");
  SerialUSB.println(sleeptime);
  if(sleeptime > 0) {
    powerdownfor(sleeptime);
  }
    
}

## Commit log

2020-02-06 major V1.3 release
    [easyhive_1_3-B.Mask.gbr, easyhive_1_3-B.Paste.gbr, easyhive_1_3-B.SilkS.gbr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]
2020-02-11 V1.2 added
    [arduino_zero.cfg, sodaq_autonomo.cfg, sodaq_explorer.cfg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]
